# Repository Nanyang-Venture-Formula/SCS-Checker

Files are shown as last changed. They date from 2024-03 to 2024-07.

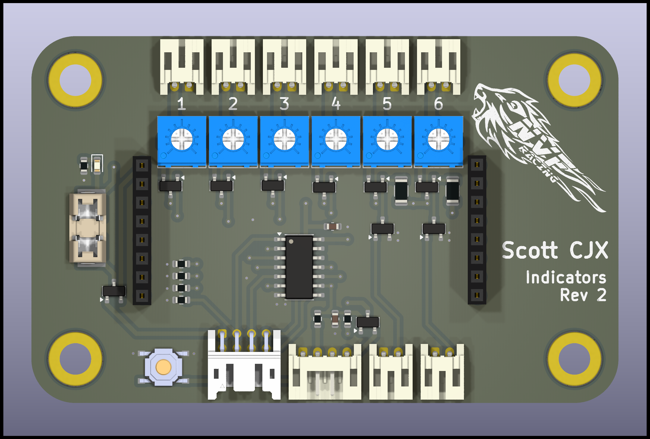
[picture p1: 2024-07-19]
docs/renders/Indicators-top.png

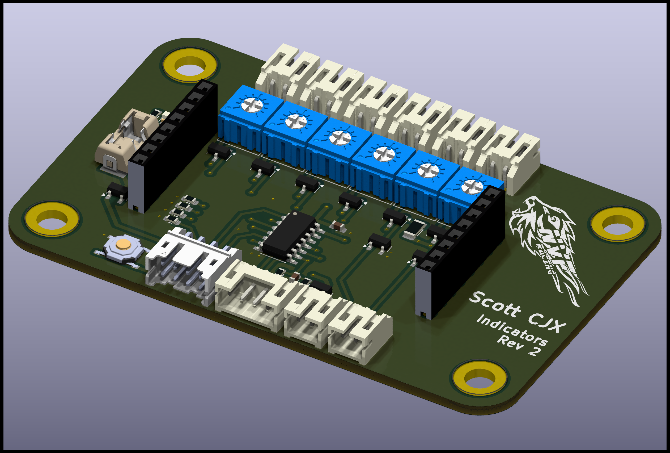
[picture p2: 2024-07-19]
docs/renders/Indicators-isometric.png

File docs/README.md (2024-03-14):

# Overview

This PCB is created to check the validity of the Systems Critical Signals (SCS) coming from other parts of the car. 

The board is designed to drive 12V LEDs.

By default, the respective outputs (meant for LEDs) are in their safe-state, that being ON.

Furthermore, to test if the board is still working, there is an additional input to a button to "test" the board's circuitry.

### Failure detection means

Since the safe-state of the car is that of LEDs being turned ON, there exists a failure where the board and/or LEDs do not recieve Vcc due to a blown fuse on this board or that the LV is not functioning.

The "test" button (a momentary NO button), when depressed, will invert the indicator light until its release. This will serve as a sanity check when debugging any potential failures. 

In the event that the signal to turn on or off the LED is faulty, the indicator will not switch its state when "test" is triggered. 

In the event that the (fused) Vcc for LEDs and the board does not supply Vcc, triggering the "test" button will have the indicators stay OFF as there is no power supplying Vcc, likewise the "test" button having an indicator on it too will lack its illumination.

### Schematic



### Connections

Refer to NVF2 Right Dashboard Packaging for the proposed hook-up schematic.

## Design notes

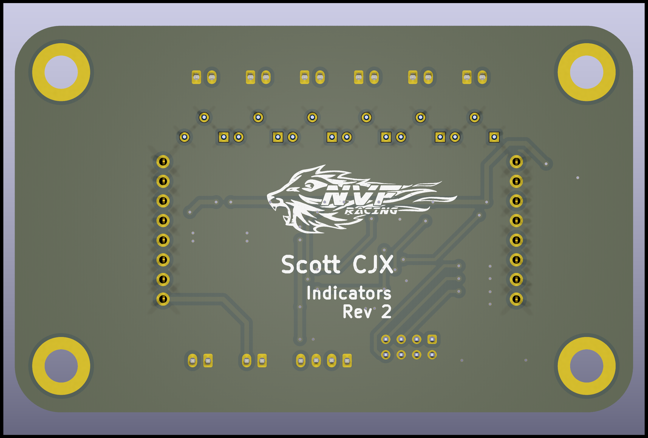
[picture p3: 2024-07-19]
docs/renders/Indicators-bottom.png

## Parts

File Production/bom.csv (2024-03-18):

Designator | Footprint | Quantity | Value | LCSC Part #
C101, C105 | 0603 | 2 | 100n | C14663
C106, C107 | 0805 | 2 | 2u2 | C377773
D101 | SOT-23 | 1 | BAV70
D102 | 0603 | 1 | LED | C434423
F101 | FUSE-Littelfuse_Nano2_154x | 1 | 0154008.DR | C206919
J101, J102, J103, J104, J106 | PH_01x02H-H | 5 | Conn_01x02
J105 | PHD_02x04H-H | 1 | SCS_IN | -
Q101, Q102, Q103, Q104, Q105 | SOT-23 | 5 | 2N7002
R101, R102, R103 | 0603 | 3 | 14k
R106, R107, R108, R114 | 0603 | 4 | 10k | C25804
R109 | 0603 | 1 | 200 | C8218
R110, R111, R112, R113 | 1206 | 4 | 120 | C17909
R115 | 0603 | 1 | 1k | C21190
RV101 | RV_Bourns_3362 | 1 | 10K
SG101 | Small-General BoardCut | 1 | ~ | -
SW101 | PushBtn_TS-1187A-B-A-B | 1 | SW_Push | C318884
SW102 | PH_01x04H-H | 1 | SW_Push_LED | -
U101 | SOIC-14_3.9x8.7mm_P1.27mm | 1 | ~
U105 | SOT-223-3_TabPin2 | 1 | AMS1117-5.0 | C6186

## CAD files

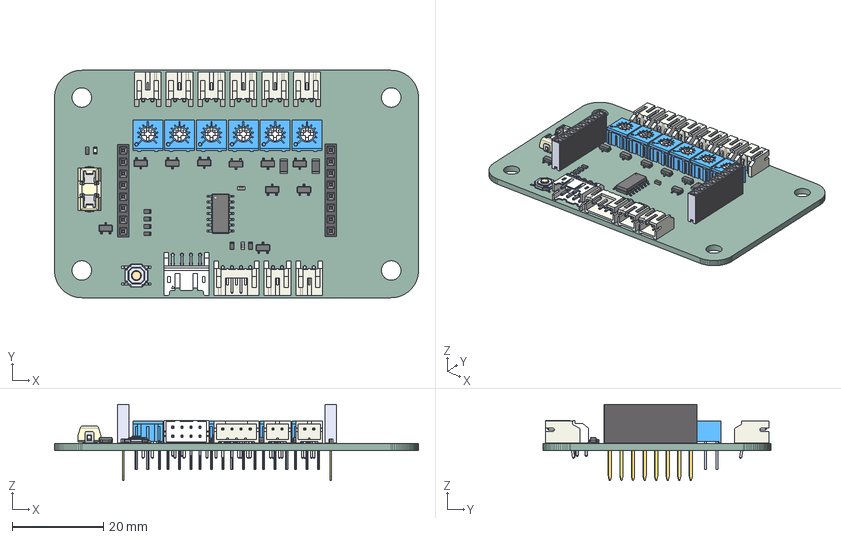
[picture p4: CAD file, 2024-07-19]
renders/NVF2-SCS-Check-Indicate.step
80.0 x 50.0 x 16.8 mm
3362P-1-103 x 6
SOT_23 x 10
R_1206_3216Metric x 2
R_0603_1608Metric x 7
01550900M
S8B-PHDSS
C_0603_1608Metric x 2
pin_header_female_2.54mm_0.1in x 2
JST_S2B_PH_K x 8
JST_S4B_PH_K
LED_0603_1608Metric
TS-1187A-B-A-B
SOIC_14_39x87mm_P127mm
NVF2-SCS-Check-Indicate_PCB

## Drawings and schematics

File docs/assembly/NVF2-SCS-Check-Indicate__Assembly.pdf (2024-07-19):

### Impedance Control: BOARD CHARACTERISTICS

# 2No None

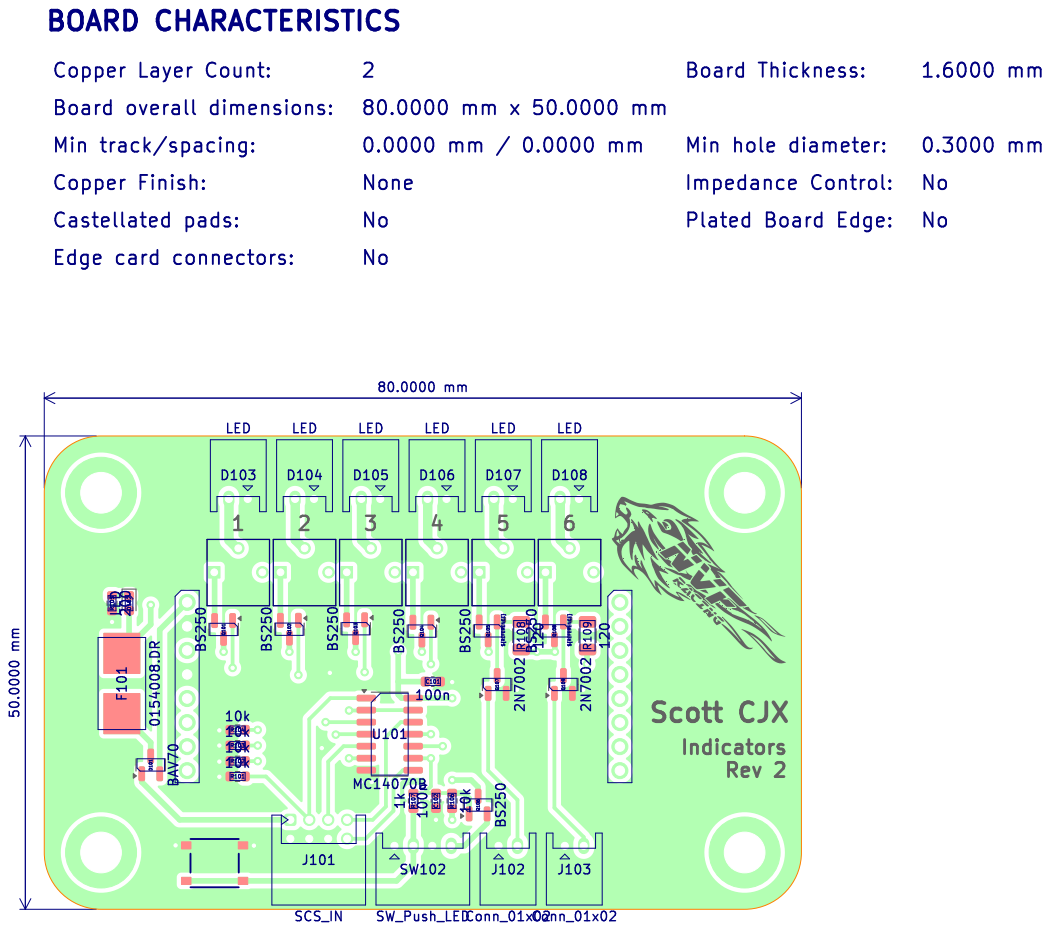
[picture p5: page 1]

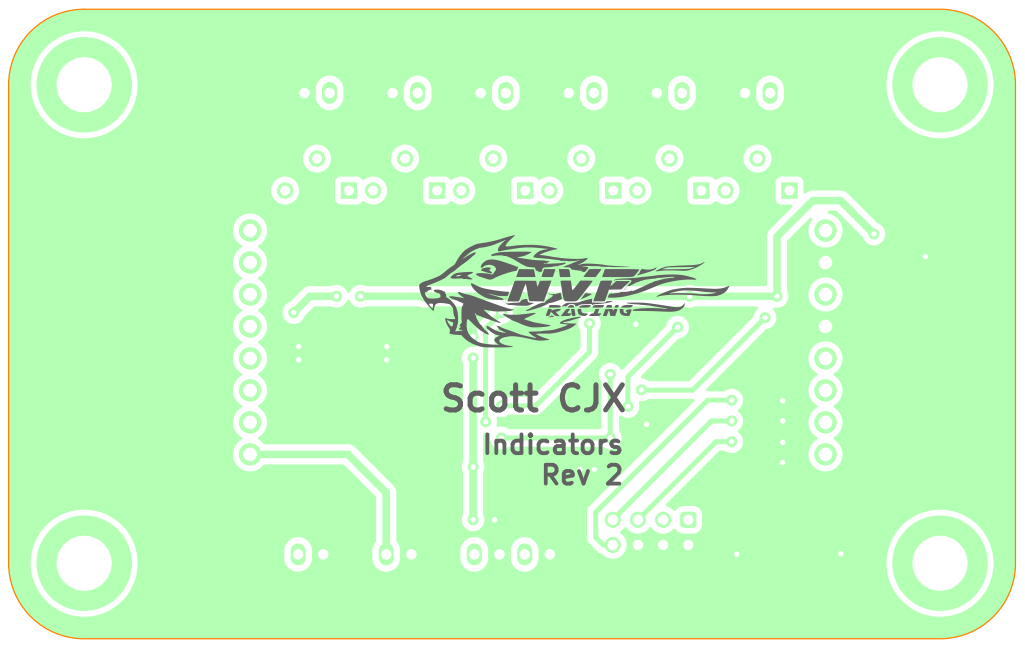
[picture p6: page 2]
Scott; CJX; Indicators Rev 2; D Date: 2024-03-19 KiCad; E.D.A. 8.0.1 Size: A4; Rev: 1; Id: 1/1 Title: Fault/Status; Indicator File: NVF2-SCS-Check-Indicate.kicad_pcb Sheet: Scott CJX

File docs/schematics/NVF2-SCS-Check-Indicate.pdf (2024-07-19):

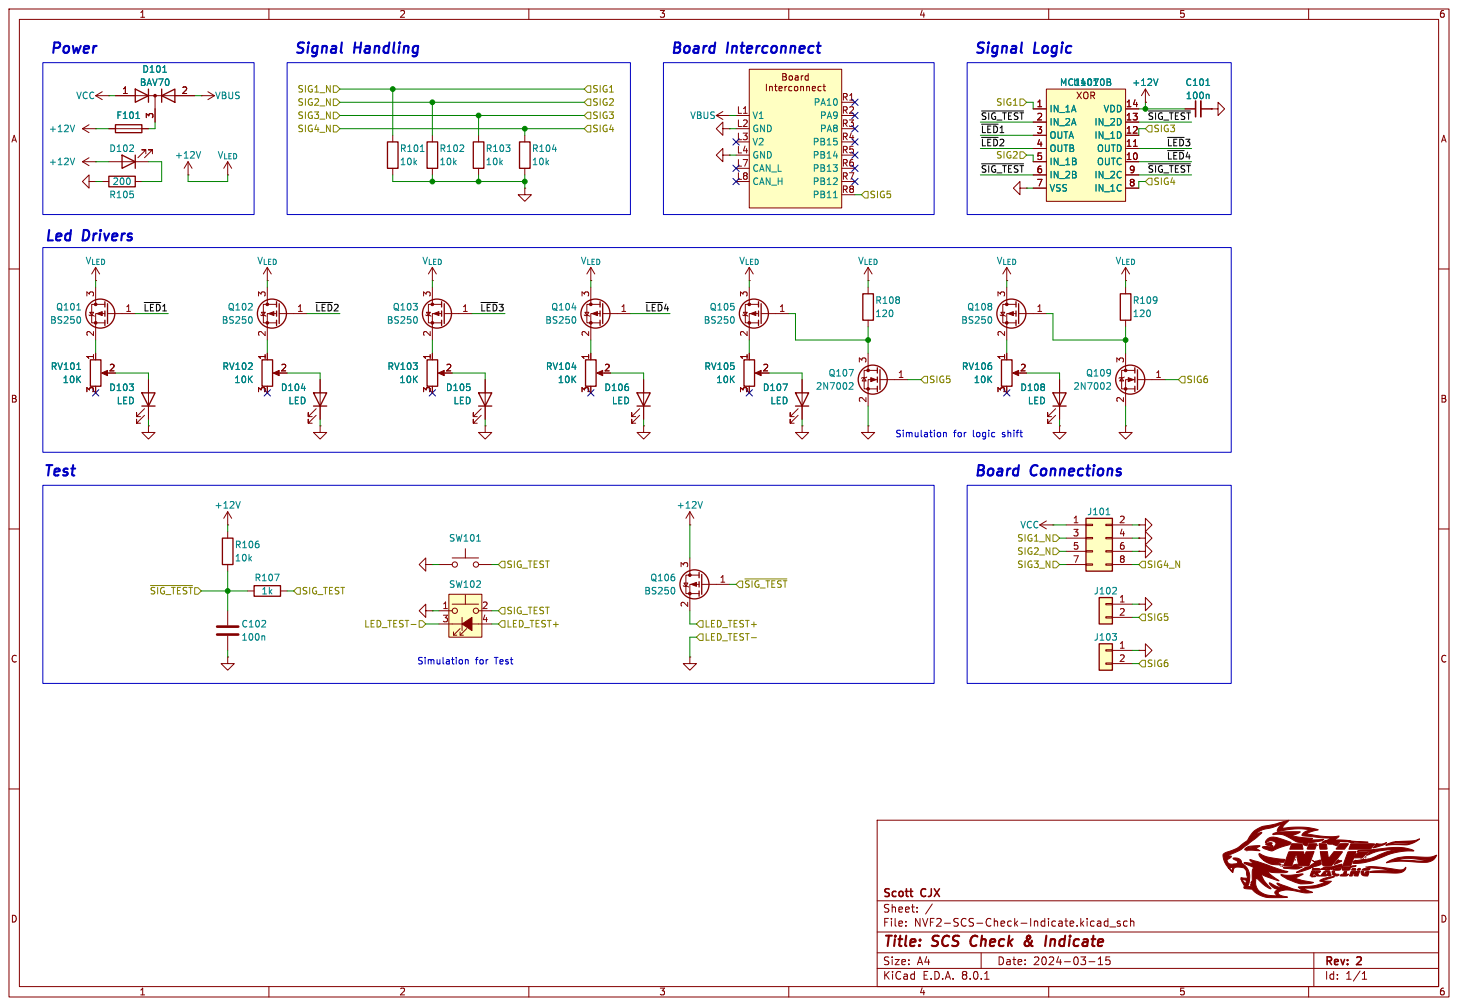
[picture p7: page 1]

File: NVF2-SCS-Check-Indicate.kicad_sch Sheet: / Scott CJX

Id: 1/1 Title: SCS Check & Indicate

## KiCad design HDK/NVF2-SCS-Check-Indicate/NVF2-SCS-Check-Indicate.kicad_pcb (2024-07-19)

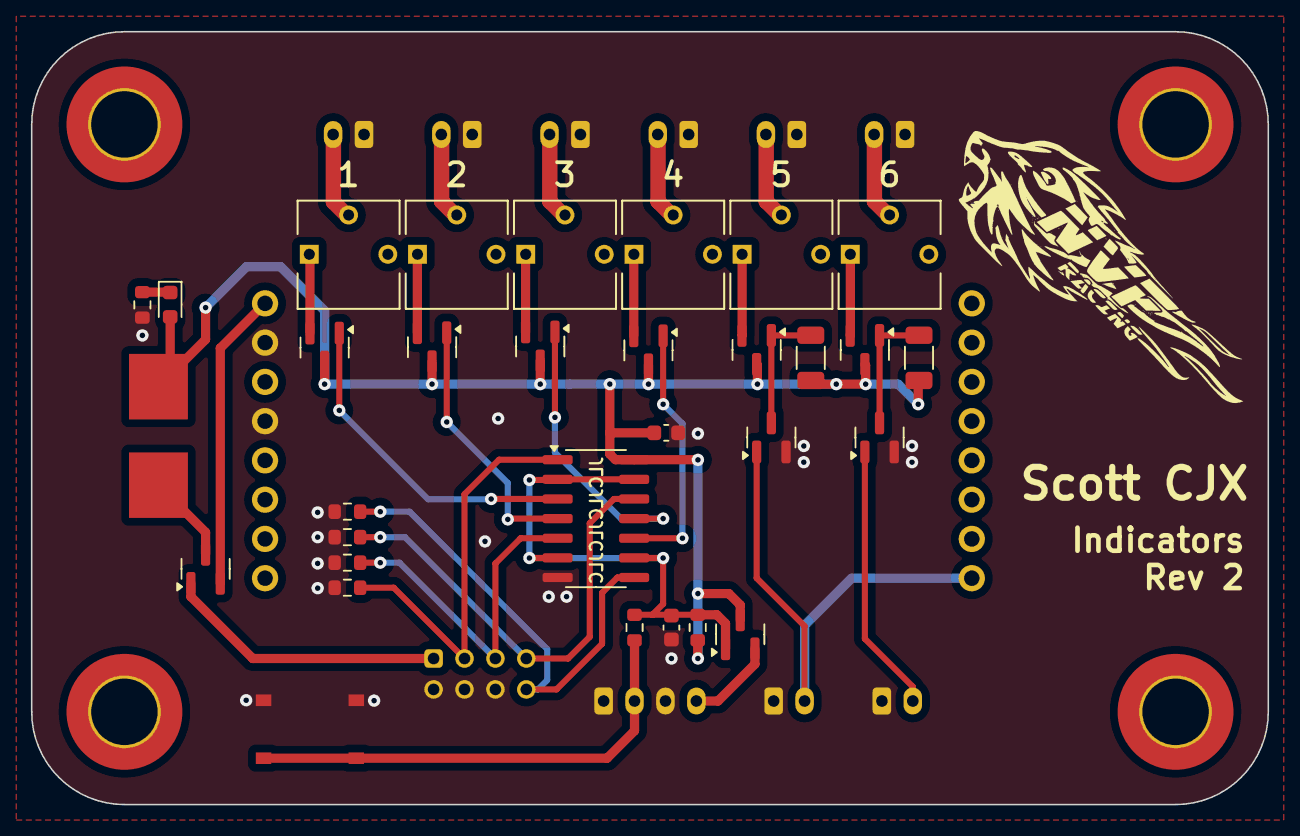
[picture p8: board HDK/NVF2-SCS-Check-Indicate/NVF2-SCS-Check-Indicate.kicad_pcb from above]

Board: 2 copper layers, 80.0 x 50.0 mm, 42 parts (0 on the bottom side), 33 nets.

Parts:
C101, C102: 100n; C_0603_1608Metric
D101: BAV70; SOT-23
D102: LED; LED_0603_1608Metric
D103, D104, D105, D106, D107, D108: LED; PH_01x02H-H
F101: 0154008.DR; FUSE-Littelfuse_Nano2_154x
J101: SCS_IN; PHD_02x04H-H
J102, J103: Conn_01x02; PH_01x02H-H
Q101, Q102, Q103, Q104, Q105, Q106, Q108: BS250; SOT-23
Q107, Q109: 2N7002; SOT-23
R101, R102, R103, R104, R106: 10k; R_0603_1608Metric
R105: 200; R_0603_1608Metric
R107: 1k; R_0603_1608Metric
R108, R109: 120; R_1206_3216Metric
RV101, RV102, RV103, RV104, RV105, RV106: 10K; RV_Bourns_3362
SG101: Small-General BoardCut
SW101: SW_Push; PushBtn_TS-1187A-B-A-B
SW102: SW_Push_LED; PH_01x04H-H
U101: MC14070B; SOIC-14_3.9x8.7mm_P1.27mm

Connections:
+12V: C101.1, D102.2 (A), F101.2, Q101.3 (D), Q102.3 (D), Q103.3 (D), Q104.3 (D), Q105.3 (D), Q106.3 (D), Q108.3 (D), R106.1, R108.1, R109.1, U101.14 (VDD)
/LED_TEST+: Q106.2 (S), SW102.4 (A)
/SIG1: J101.3, R101.1, U101.1 (IN_1A)
/SIG2: J101.5, R102.1, U101.5 (IN_1B)
/SIG3: J101.7, R103.1, U101.12 (IN_1D)
/SIG4: J101.8, R104.1, U101.8 (IN_1C)
/SIG5: J102.2, Q107.1 (G), SG101.R8 (PB11)
/SIG6: J103.2, Q109.1 (G)
/SIG_TEST: R107.2, SW101.1, SW102.2
/~LED1: Q101.1 (G), U101.3 (OUTA)
/~LED2: Q102.1 (G), U101.4 (OUTB)
/~LED3: Q103.1 (G), U101.11 (OUTD)
/~LED4: Q104.1 (G), U101.10 (OUTC)
/~SIG_TEST: C102.1, Q106.1 (G), R106.2, R107.1, U101.2 (IN_2A), U101.6 (IN_2B), U101.9 (IN_2C), U101.13 (IN_2D)
GND: C101.2, C102.2, D103.1 (K), D104.1 (K), D105.1 (K), D106.1 (K), D107.1 (K), D108.1 (K), J101.2, J101.4, J101.6, J102.1, J103.1, Q107.2 (S), Q109.2 (S), R101.2, R102.2, R103.2, R104.2, R105.1, SG101.L2 (GND), SG101.L4 (GND), SW101.2, SW102.1, SW102.3 (K), U101.7 (VSS)
unnamed: D101.3 (K), F101.1
unnamed: D102.1 (K), R105.2
unnamed: D103.2 (A), RV101.2
unnamed: D104.2 (A), RV102.2
unnamed: D105.2 (A), RV103.2
unnamed: D106.2 (A), RV104.2
unnamed: D107.2 (A), RV105.2
unnamed: D108.2 (A), RV106.2
unnamed: Q101.2 (S), RV101.1
unnamed: Q102.2 (S), RV102.1
unnamed: Q103.2 (S), RV103.1
unnamed: Q104.2 (S), RV104.1
unnamed: Q105.1 (G), Q107.3 (D), R108.2
unnamed: Q105.2 (S), RV105.1
unnamed: Q108.1 (G), Q109.3 (D), R109.2
unnamed: Q108.2 (S), RV106.1
VBUS: D101.2 (A), SG101.L1 (V1)
VCC: D101.1 (A), J101.1

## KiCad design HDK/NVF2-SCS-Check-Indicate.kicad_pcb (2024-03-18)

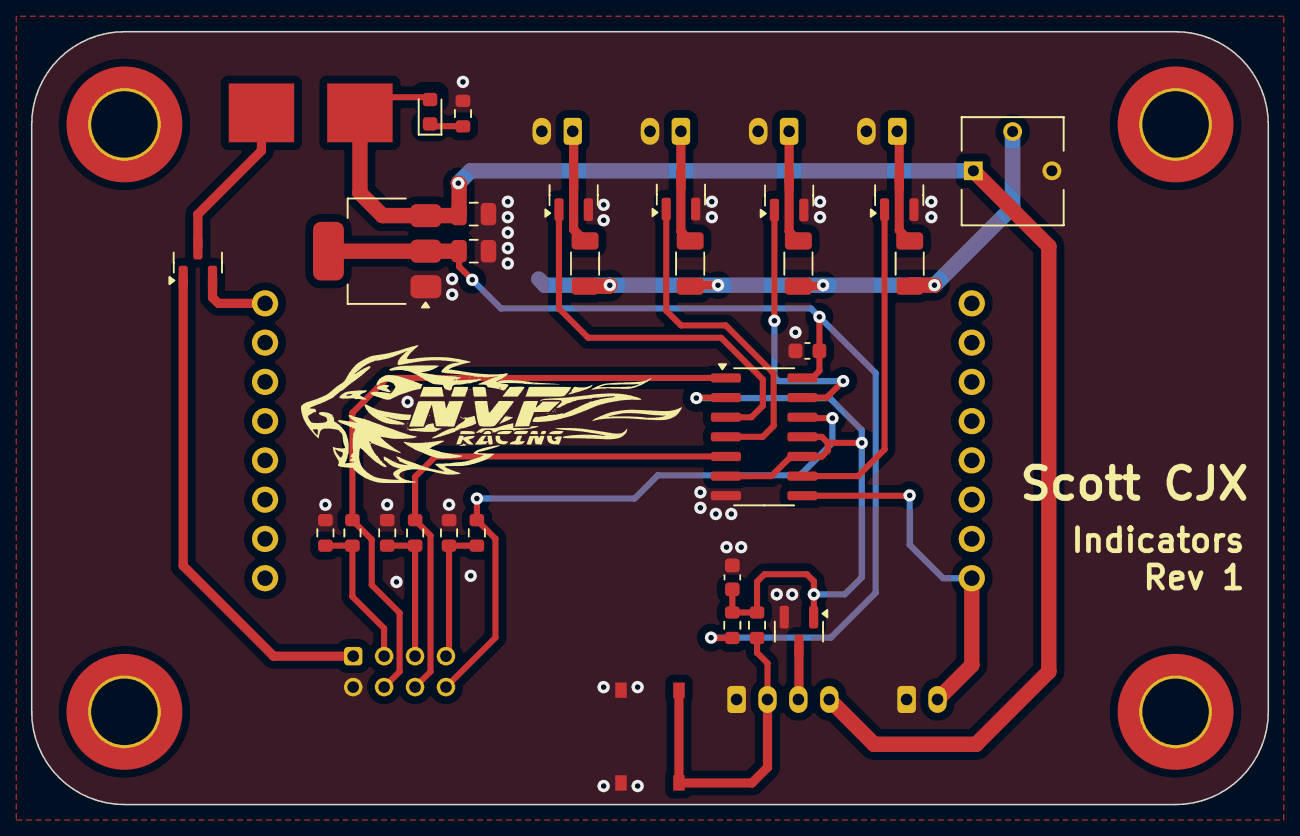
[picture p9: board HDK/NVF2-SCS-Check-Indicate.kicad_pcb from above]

Board: 2 copper layers, 80.0 x 50.0 mm, 37 parts (0 on the bottom side), 26 nets.

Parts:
C101, C105: 100n; C_0603_1608Metric
C106, C107: 2u2; C_0805_2012Metric
D101: BAV70; SOT-23
D102: LED; LED_0603_1608Metric
F101: 0154008.DR; FUSE-Littelfuse_Nano2_154x
J101, J102, J103, J104, J106: Conn_01x02; PH_01x02H-H
J105: SCS_IN; PHD_02x04H-H
Q101, Q102, Q103, Q104, Q105: 2N7002; SOT-23
R101, R102, R103: 14k; R_0603_1608Metric
R106, R107, R108, R114: 10k; R_0603_1608Metric
R109: 200; R_0603_1608Metric
R110, R111, R112, R113: 120; R_1206_3216Metric
R115: 1k; R_0603_1608Metric
RV101: 10K; RV_Bourns_3362
SG101: Small-General BoardCut
SW101: SW_Push; PushBtn_TS-1187A-B-A-B
SW102: SW_Push_LED; PH_01x04H-H
U101: SOIC-14_3.9x8.7mm_P1.27mm
U105: AMS1117-5.0; SOT-223-3_TabPin2

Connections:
+5V: C101.1, C107.1, R114.1, U101.14 (VDD), U105.2 (VO)
+12V: C106.1, D102.2 (A), F101.2, RV101.1, SW102.4 (A), U105.3 (VI)
/LED_TEST-: Q105.3 (D), SW102.3 (K)
/SIG1: J105.4, R101.2, U101.1 (IN_1A)
/SIG1_N: J105.3, R101.1, R108.1
/SIG2: J105.6, R102.2, U101.5 (IN_1B)
/SIG2_N: J105.5, R102.1, R107.1
/SIG3: J105.8, R103.2, U101.12 (IN_2C)
/SIG3_N: J105.7, R103.1, R106.1
/SIG4: J106.2, SG101.R8 (PB11), U101.8 (IN_2D)
/SIG_TEST: R115.2, SW101.1, SW102.2
/~LED1: Q101.1 (G), U101.3 (OUTA)
/~LED2: Q102.1 (G), U101.4 (OUTB)
/~LED3: Q103.1 (G), U101.13 (OUTC)
/~LED4: Q104.1 (G), U101.9 (OUTD)
/~SIG_TEST: C105.1, Q105.1 (G), R114.2, R115.1, U101.2 (IN_2A), U101.6 (IN_2B), U101.10 (IN_1D), U101.11 (IN_1C)
GND: C101.2, C105.2, C106.2, C107.2, J101.2, J102.2, J103.2, J104.2, J105.2, J106.1, Q101.2 (S), Q102.2 (S), Q103.2 (S), Q104.2 (S), Q105.2 (S), R106.2, R107.2, R108.2, R109.1, RV101.3, SW101.2, SW102.1, U101.7 (VSS), U105.1 (GND)
unnamed: D101.3 (K), F101.1
unnamed: D102.1 (K), R109.2
unnamed: J101.1, Q101.3 (D), R110.2
unnamed: J102.1, Q102.3 (D), R111.2
unnamed: J103.1, Q103.3 (D), R112.2
unnamed: J104.1, Q104.3 (D), R113.2
VBUS: D101.2 (A), SG101.L1 (V1)
VCC: D101.1 (A), J105.1
V_{LED}: R110.1, R111.1, R112.1, RV101.2

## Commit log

2024-03-06 freeze rev1
    [NVF2-SCS-Check-Indicate.kicad_pcb, NVF2-SCS-Check-Indicate.kicad_sch]
2024-03-18 updated docs
    [NVF2-SCS-Check-Indicate.step, bom.csv, designators.csv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]
2024-07-19 final rev2
    [NVF2-SCS-Check-Indicate-B_Cu.gbr, NVF2-SCS-Check-Indicate-B_Mask.gbr, NVF2-SCS-Check-Indicate-B_Paste.gbr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]
